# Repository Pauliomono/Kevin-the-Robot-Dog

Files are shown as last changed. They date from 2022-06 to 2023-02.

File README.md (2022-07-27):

# Kevin-the-Robot-Dog

Kevin the Robot Dog is a quadruped I created for a final design project at the University of Notre Dame.

Check him out on Youtube:

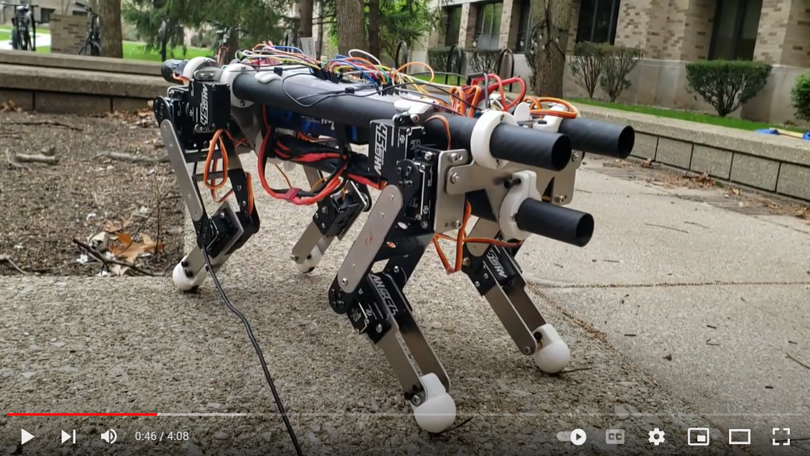
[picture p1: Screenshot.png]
IMAGE ALT TEXT HERE (https://www.youtube.com/watch?v=h35KHhktcEo&t)


For more information check out the final report written on Kevin.

- See Final_Report/Automation_and_Controls_Final_Project_Report.pdf

Recent Changes:

- complete overhaul of code: migrated to PlatformIO in vscode, reorganised functions into separate files
- initial addition of remote control using bluetooth serial (can change modes, walk forward/back & steer)
- improved interpolation for foot positions: switched from linear interpolation to cubic spline interpolation for improved velocity and acceleration control

Active Development:

- adding more remote functionality: telemetry reports to remote, remote realtime PID tuning
- tweaking walking gait/motion to get smoother motion
- adding trim mode (currently drifts instead of staying in one place)

Future plans include:

- Bluetooth remote control
- reworking the entire wiring system (including custom PCB) and battery monitoring circuitry
- overhaul balance control with a more complex model (using analyital dynamics to generate EOMs) of the system & additional tuning
- possible force control? either though current sensors on servos or pressure sensors on feet
- googley eyes to make him cuter
- expanded motion capabilities (jumping, rough surfaces & inclines, possibly stairs)

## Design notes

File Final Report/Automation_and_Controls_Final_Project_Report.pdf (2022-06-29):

AME 40453: Final Project
Technical Memo
Date Submitted: April 28 2022 Dates Performed: Spring 2022 To: Prof. Rumbach
From: Paul Mellor
Subject: Final Project Report

For the Automation and Controls Final Design Project, my project was to build a robotic dog. I

had three goals for this project. My first goal was that the dog would be able to walk forward

& backward and turn left & right on flat surfaces. My second goal was for the robot to actively

balance, so that it did not fall over trying to walk. My third goal was to be able to drive the robot;

I wanted to be able to send movement commands and have the dog move accordingly.

To attack these goals, I came up with the design below.

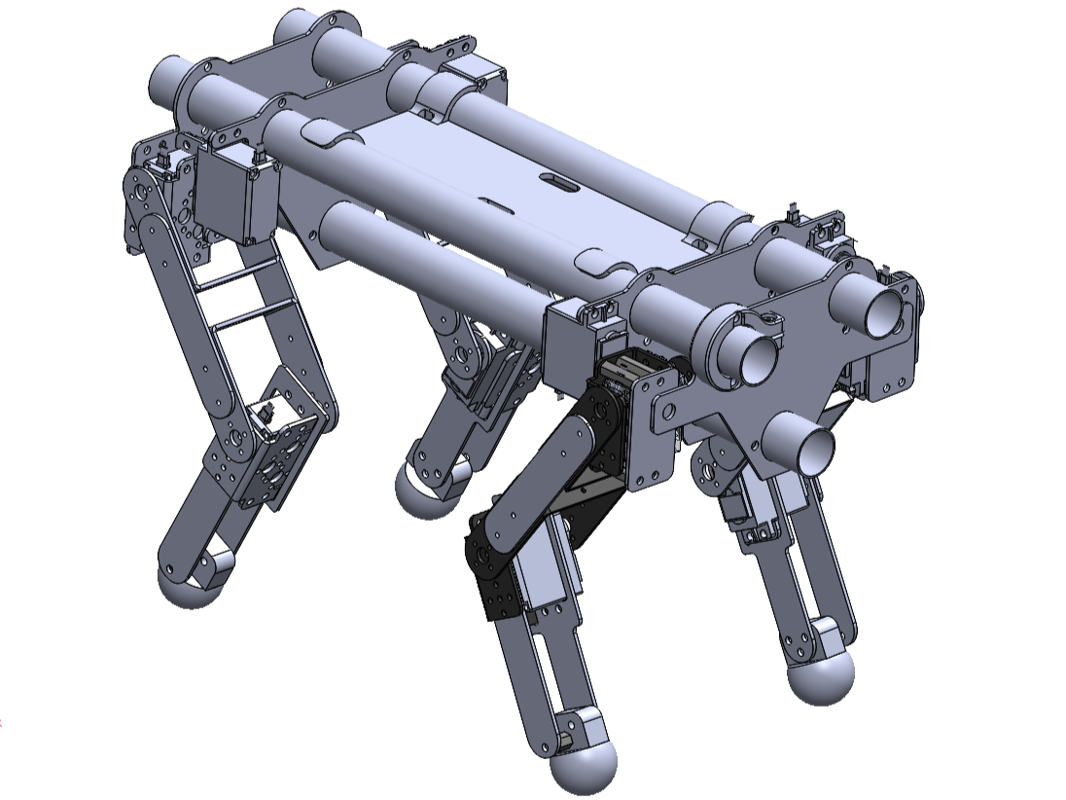
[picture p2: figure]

Figure 1: CAD Model of the Robot

The dog is symmetrical, with 4 identical legs having the knee joint facing the center of the dog.

Each leg has a shoulder joint with 2 DOFs (degrees of freedom) so that the leg can move forward

& backward and left & right. Each joint is driven by a servo motor. Servos are both high torque,

and can be positioned accurately. The construction consists primarily of off the shelf brackets, and

2D fabricated plates. Symmetry and reliance on 2D components greatly simplified the fabrication

process (most components were cut on a waterjet). Additionally, symmetry allowed any kinematic

models for one leg to be applicable to all legs.

The robot’s motion is based on positioning the legs. To walk, each leg steps through 6 way-points

(See Figure 2), and has a specified time to get from 1 point to the next.

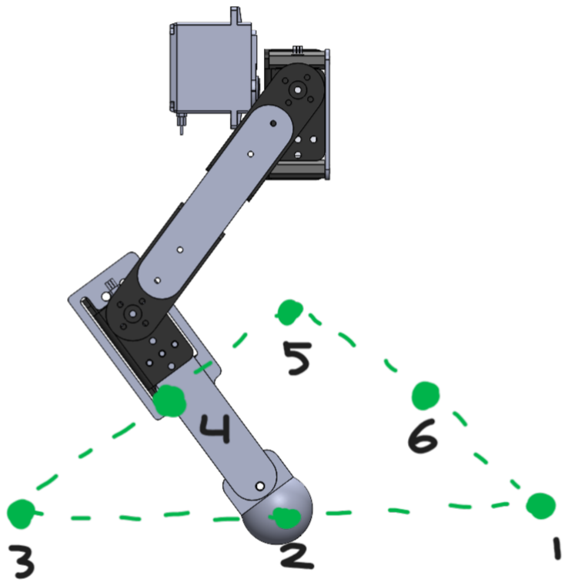
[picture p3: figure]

Figure 2: Path/Points of the Leg’s Walking Motion

To walk, the legs diagonal from one another move in sync, while the opposite two legs are 180◦

out of phase (i.e. if one set of diagonal legs is at point 1, the other set is at point 4). The points are

all timed so that the leg spends half the time on the ground (points 1, 2, 3), and half the time off

the ground (points 4, 5, 6).

Since my approach to moving the legs was to position them in xyz coordinates, I needed an inverse

kinematics model to get the motor angles as a function of xyz coordinates for each leg. The inverse

kinematics was solved using trigonometry (see Figure 3). This was possible because there are only

3 DOF, and because there is a limited area in which the leg can actually move.

To solve for θshoulder1 (the shoulder joint moving in the yz plane) using xyz coordinates (as depicted

in figure 2) the equation below is used.

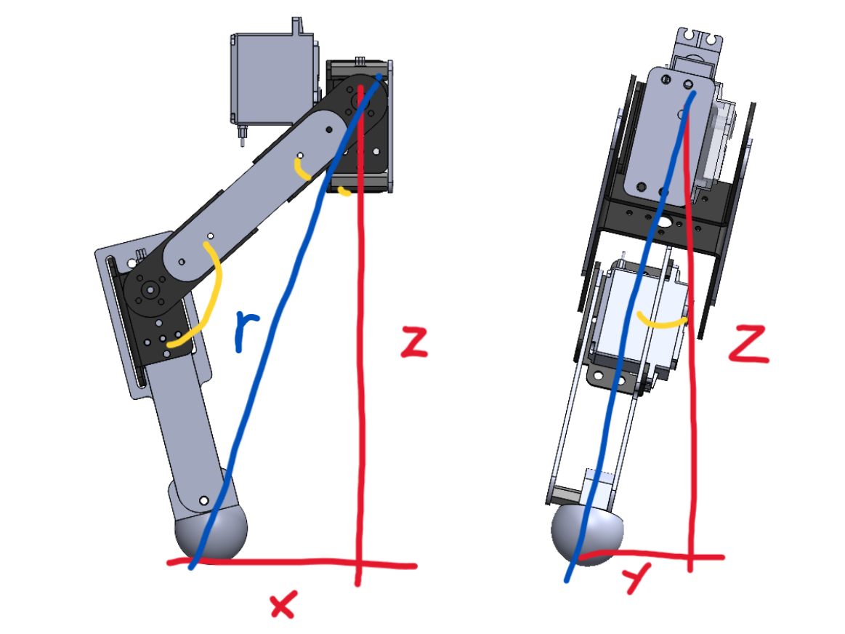
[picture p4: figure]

Figure 3: Trig Used to Calculate Inverse Kinematics

θshoulder1 = arctan(

y
z
) | (1)

To solve for θshoulder2 (the shoulder joint moving in the xz plane) and θknee an intermediate length

r is calculated by:

r =

p
z

2 +x

2
(2)

This enabled my to use law of cosines to solve for θshoulder2 and θknee below.

θshoulder2 = arccos(

r

2

2Lr

)−arctan(

x
z
); | (3)

θknee = arccos(

2L

2 −r

2

2L

2

); | (4)

where L is the length of the limbs (both limbs are equal length).

To actively balance the robot, a controller was designed to maintain 0◦of pitch and roll by keeping the 4 feet of the robot centered below the COM (center of mass). An accelerometer/gyroscopic

sensor was placed on the body of the robot, and returned θpitch and θroll of the robot. To control

the pitch, the x position of the legs were adjusted using the PID control equation below:

x = xopenloop +hsin(kp(θpitchs −θpitch) +kI

Z
(θpitchs −θpitch)dt +kd∆θpitch) | (5)

where xopenloop is the x value before the balance calculation, h is the height of the shoulder joint

to the ground, θpitchs

is the target pitch angle (0◦ ) and kp, kI and kd are the PID control constants.

SImilarly, to control the roll, the y position of the legs were adjusted using the PID control equation

below:

y = yopenloop +hsin(kp(θrolls −θroll) +kI

Z
(θrolls −θroll)dt +kd∆θroll) | (6)

here yopenloop is the x value before the balance calculation, h is the height of the shoulder joint to

the ground, θpitchs

is the target pitch angle (0◦ ) and kp, kI and kd are different PID control constants.

The resulting robot is shown below.

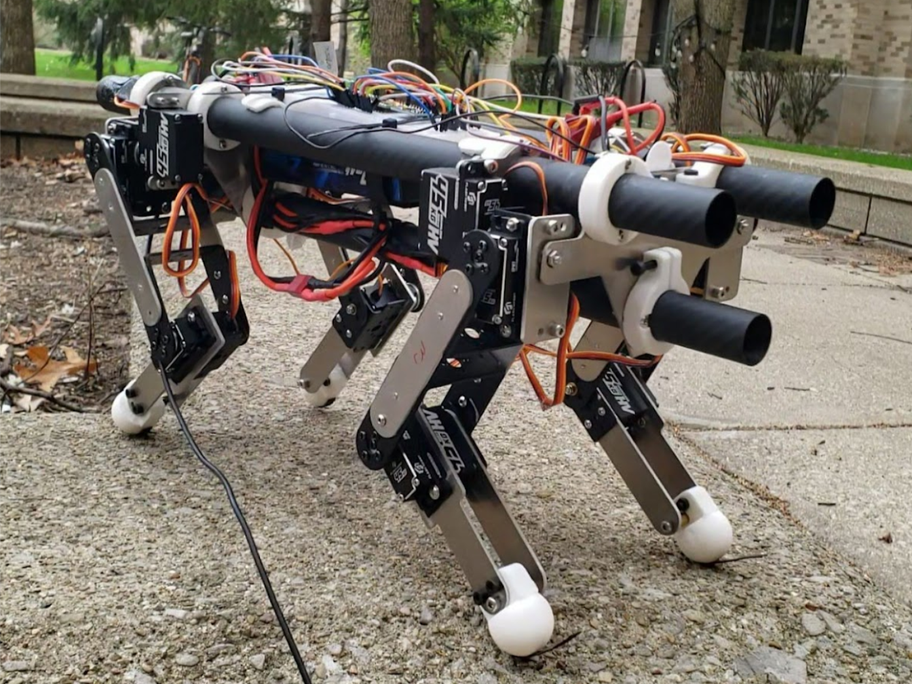
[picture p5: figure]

Figure 4: Photo of the Final Robot

It effectively met the goals initially set out for this project. The dog can walk forward & backward

and turn left & right without falling over. The balance controller is effective enough that it can even

handle some uneven surfaces. It takes serial inputs sent from a laptop to determine what direction

to move.

There are still a number of issues with the robot. First, it is not completely remote control. The

dog is still tethered to a laptop to send commands. This would make the robot much easier to

use. Second, electrical noise occasionally interferes with the signals to the motors, causing them to

glitch out. Shielding and shortening the signal wires would make leg movements more consistent

and predictable. Third, the balance control is still rudimentary. If a more sophisticated controller

was used, the robot could move more smoothly and handle significantly rougher terrain.

Overall, I am pleased with the results for this project.

References:

[1] James Bruton Youtube Channel, https://youtu.be/aDlHz0W0R44
[2] James Bruton Github, https://github.com/XRobots/miniDogV2
[3] MPU6050 Github, https://github.com/electroniccats/mpu6050

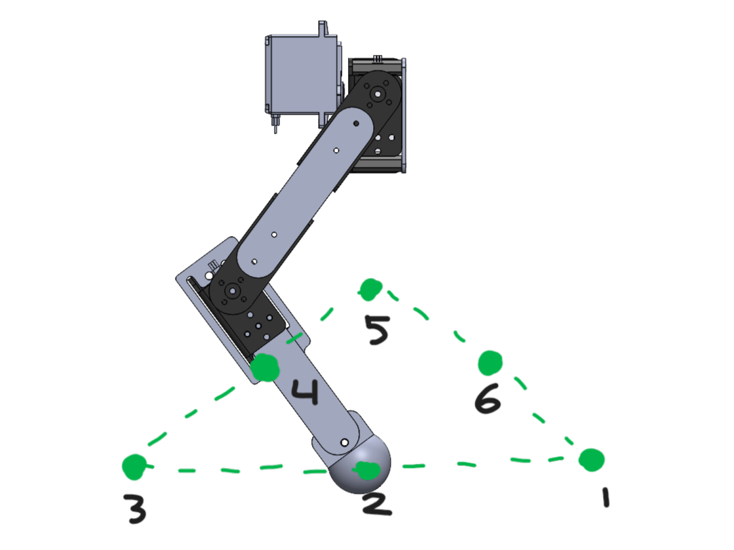
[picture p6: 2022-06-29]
Final Report/Screenshot (202).png

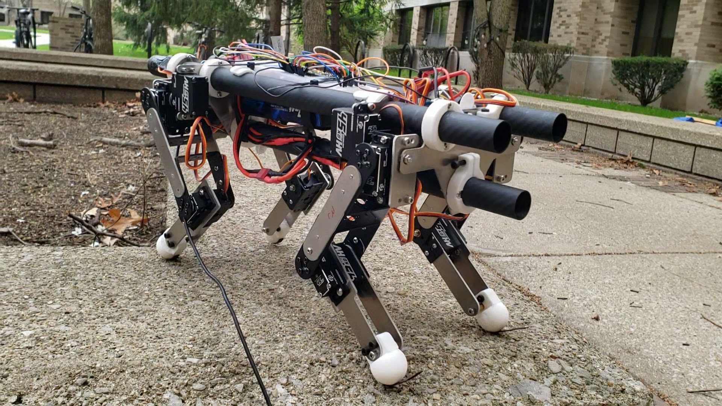
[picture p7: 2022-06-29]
20220424_132255_exported_5930.jpg

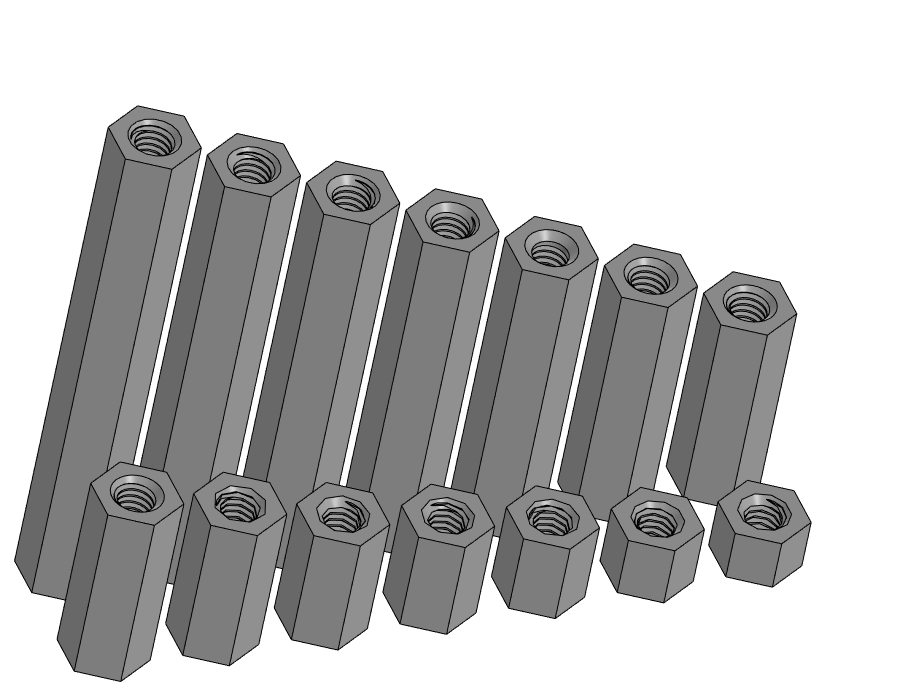
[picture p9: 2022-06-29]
CAD Files/hex-spacer-standoff-nut-m4-l5-l50-1.snapshot.3/hex spacer standoff nut M4 L5-L50.png

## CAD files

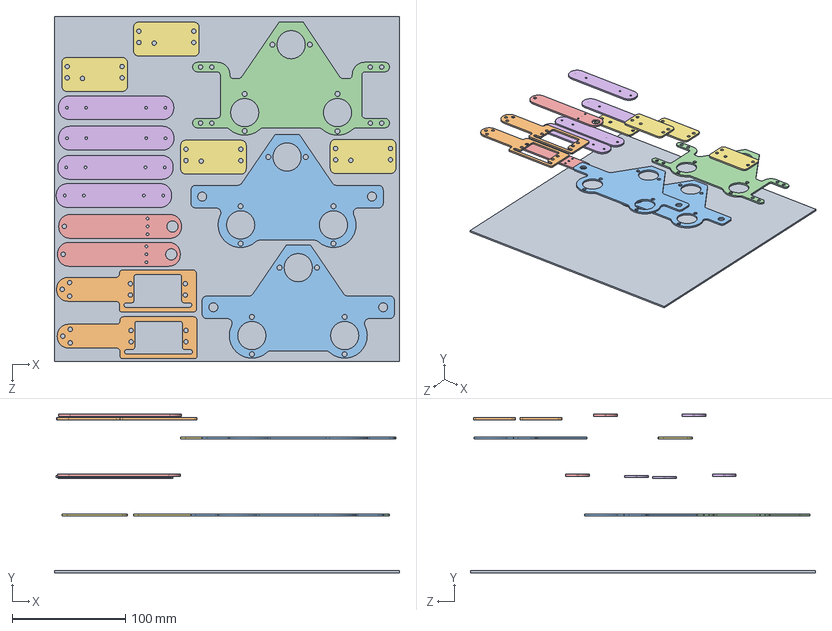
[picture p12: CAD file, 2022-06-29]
CAD Files/DXF files/waterjet_setup.SLDASM
304.8 x 140.1 x 304.8 mm
stock
leg_lower_1 x 2
hip_frame_2 x 2
hip_frame_1
leg_lower_2 x 2
leg_upper_1 x 4
hip_1 x 4

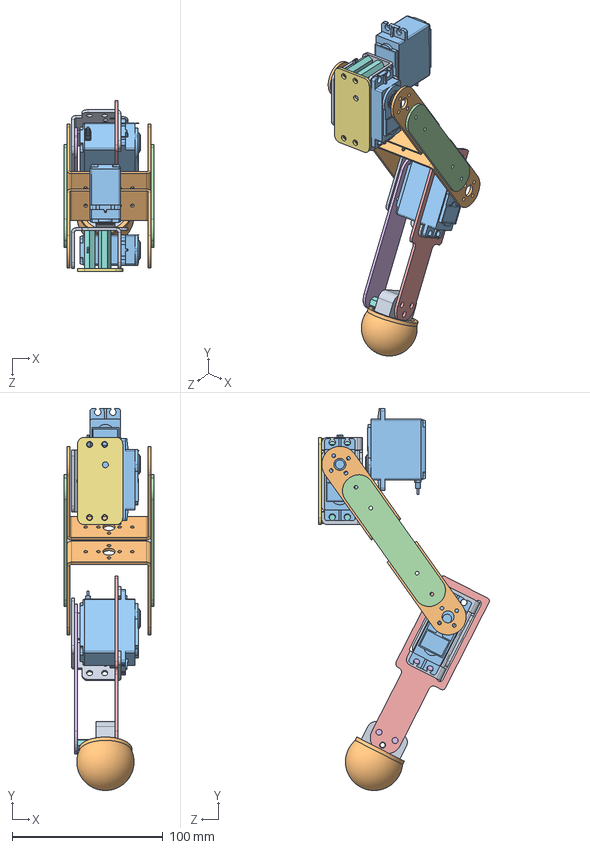
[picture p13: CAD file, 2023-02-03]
CAD Files/leg.SLDASM
60.0 x 253.4 x 113.4 mm
Multi Purpose Bracket x 2
U Long Bracket x 2
Parça2 - Kopya x 3
leg_upper_1 x 2
leg_lower_1
leg_lower_2
hip_1
hex spacer standoff nut M4 L25.stp x 5
foot
foot_grip

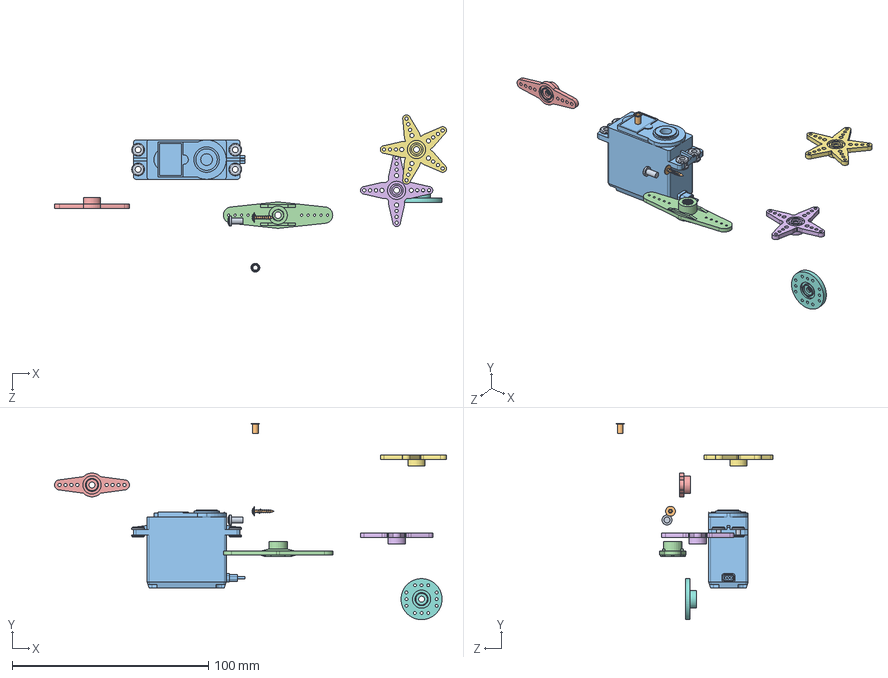
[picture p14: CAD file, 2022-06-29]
CAD Files/servo motor/Montaj2.SLDASM
199.6 x 100.0 x 80.1 mm
Parça10
parça11,
Parça2
Parça3
Parça4
Parça5
Parça6
Parça8
parça9 x 4

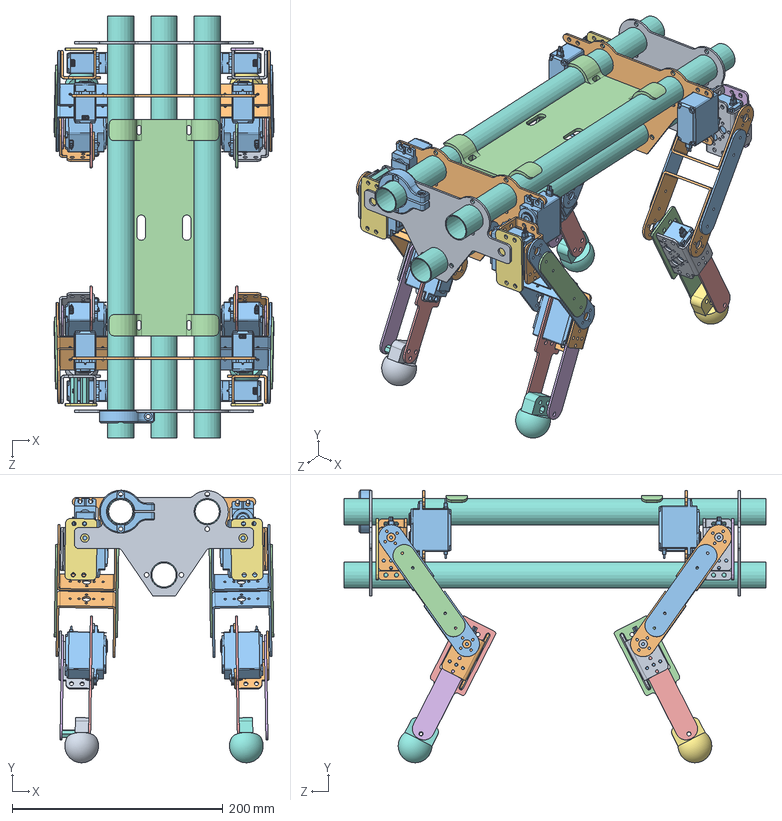
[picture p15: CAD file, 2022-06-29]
CAD Files/Robo_Doggo.SLDASM
208.1 x 258.4 x 400.0 mm
Multi Purpose Bracket x 2
U Long Bracket x 2
Parça2 - Kopya x 12
leg_upper_1 x 2
leg_lower_1
leg_lower_2
hip_1
hex spacer standoff nut M4 L25.stp x 5
foot
MirrorMulti Purpose Bracket x 4
MirrorU Long Bracket x 4
Mirrorleg_upper_1 x 4
Mirrorleg_lower_1 x 2
Mirrorleg_lower_2 x 2
Mirrorhip_1 x 2
Mirrorfoot x 2
MirrorMirrorMulti Purpose Bracket x 2
MirrorMirrorU Long Bracket x 2
MirrorMirrorleg_upper_1 x 2
MirrorMirrorleg_lower_1
MirrorMirrorleg_lower_2
MirrorMirrorhip_1
MirrorMirrorfoot
frame_tube_1 x 3
hip_frame_2 x 2
hip_frame_1 x 2
tube_clamp_1
electronics_mount

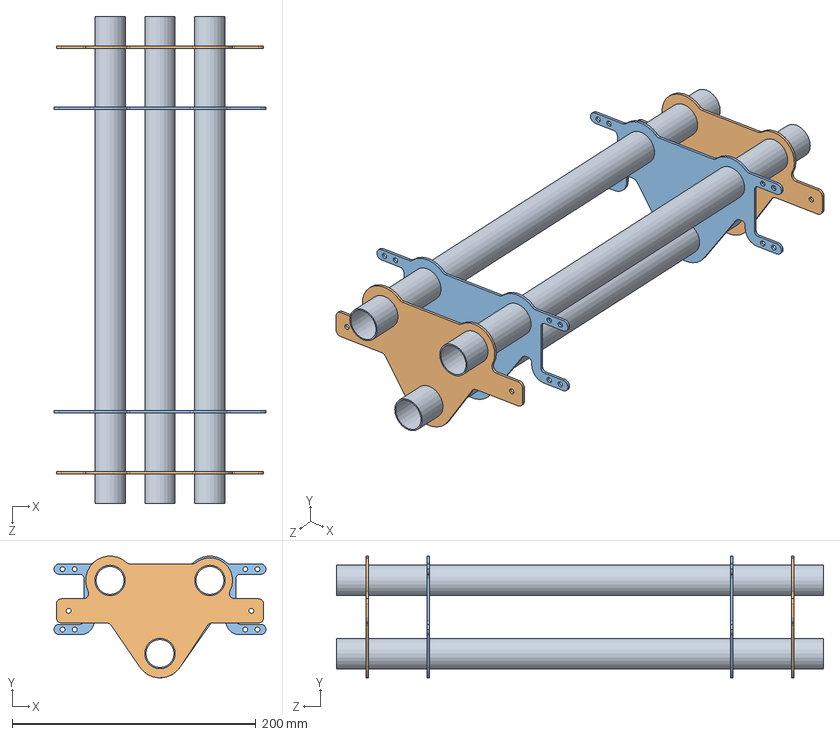
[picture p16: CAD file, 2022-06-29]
CAD Files/Frame.SLDASM
174.0 x 99.8 x 400.0 mm
frame_tube_1 x 3
hip_frame_2 x 2
hip_frame_1 x 2

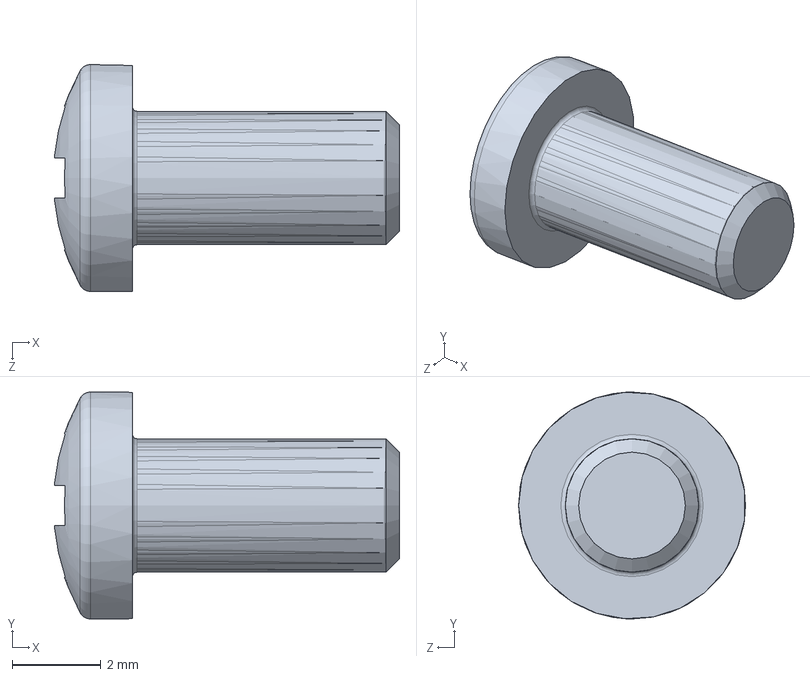
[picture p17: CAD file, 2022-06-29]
CAD Files/servo motor/parça12.SLDPRT
7.75 x 5.10 x 5.10 mm

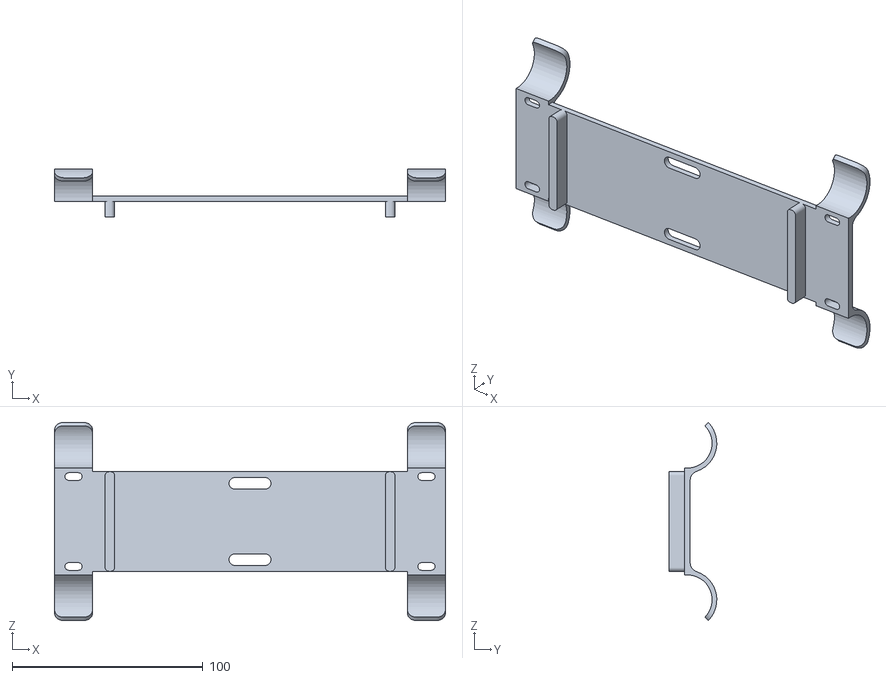
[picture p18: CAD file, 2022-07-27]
CAD Files/STL Files/electronics_mount_v2.STL
205.0 x 25.0 x 103.9

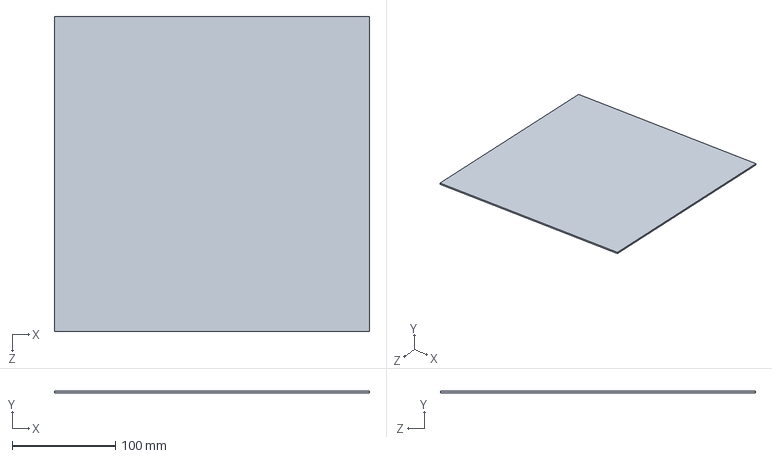
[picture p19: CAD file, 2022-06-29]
CAD Files/DXF files/stock.SLDPRT
304.8 x 2.00 x 304.8 mm

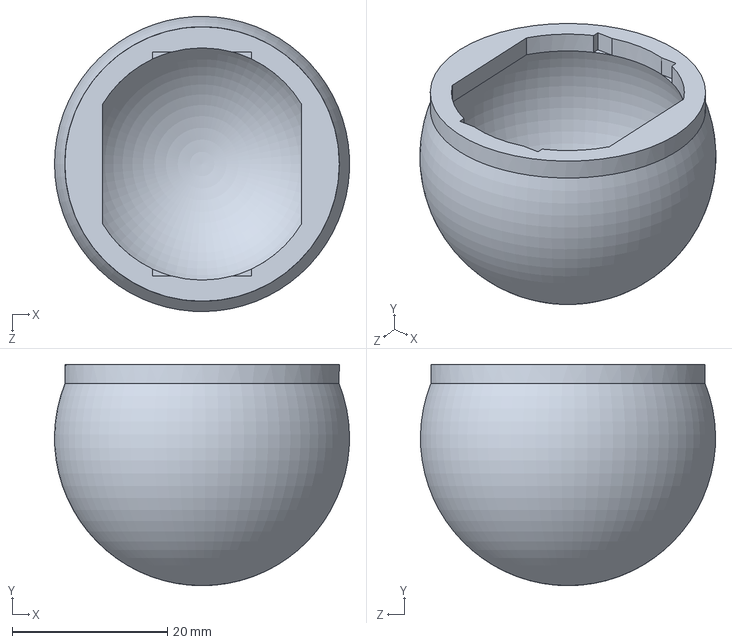
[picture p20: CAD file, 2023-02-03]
CAD Files/foot_grip.SLDPRT
38.0 x 28.5 x 38.0 mm

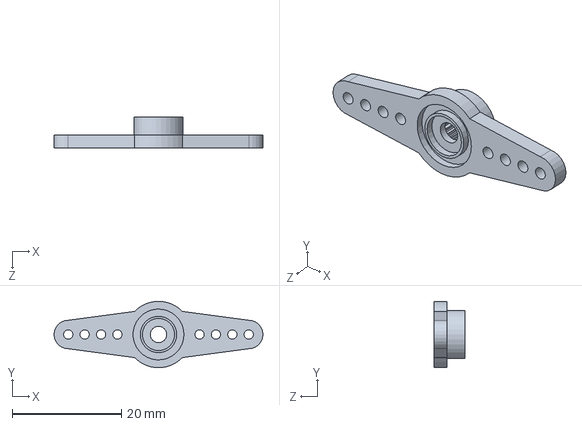
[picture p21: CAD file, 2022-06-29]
CAD Files/servo motor/Parça4.SLDPRT
38.2 x 12.1 x 5.60 mm

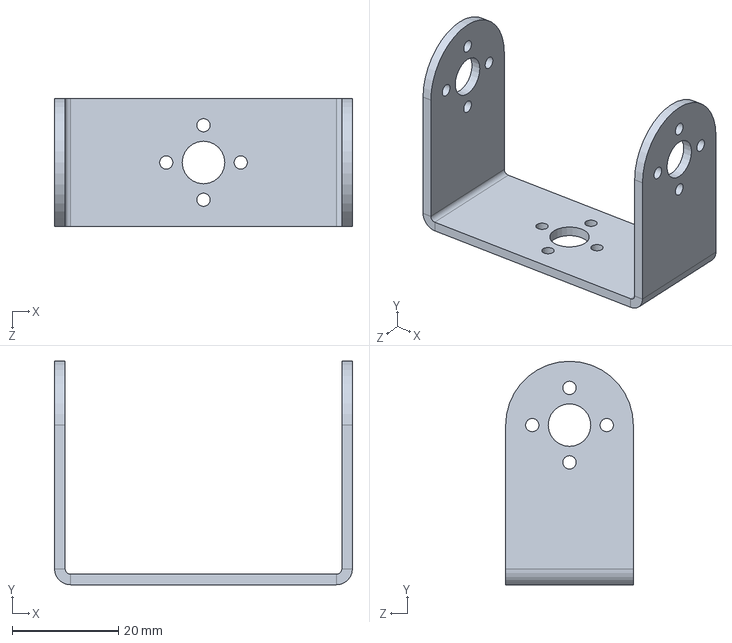
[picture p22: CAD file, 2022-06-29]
CAD Files/servo-brackets-2.snapshot.3/U Bracket.SLDPRT
56.0 x 42.0 x 24.0 mm

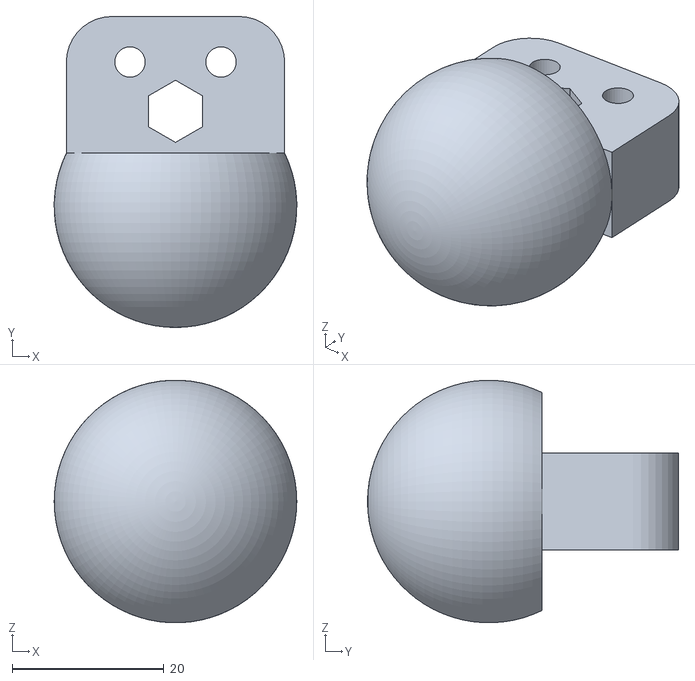
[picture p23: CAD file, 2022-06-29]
CAD Files/STL Files/foot.STL
32.0 x 41.0 x 32.0

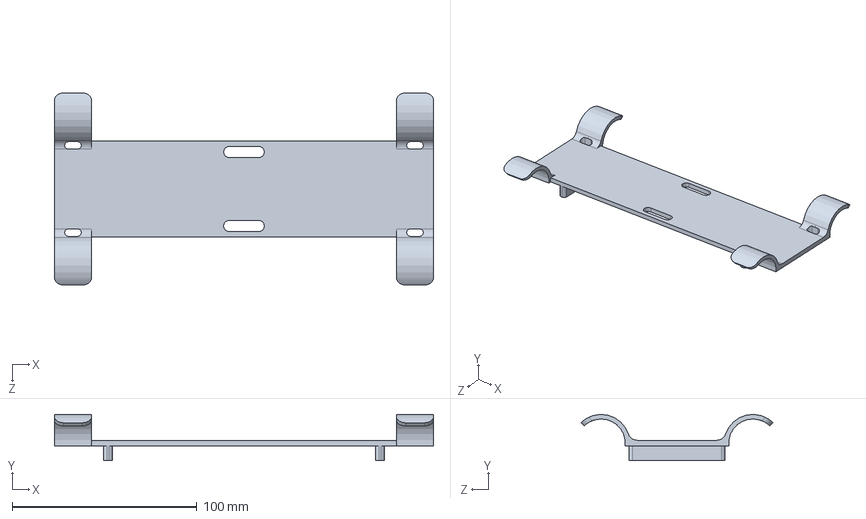
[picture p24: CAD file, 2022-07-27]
CAD Files/electronics_mount.SLDPRT
205.0 x 25.0 x 103.9 mm

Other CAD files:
CAD Files/Mirrorleg1.SLDASM
CAD Files/MirrorMirrorleg.SLDASM
CAD Files/Mirrorleg.SLDASM
CAD Files/servo-brackets-2.snapshot.3/MirrorMirrorU Long Bracket.SLDPRT
CAD Files/DXF files/waterjet_path_2.DXF
CAD Files/98434A706_18-8 Stainless Steel Female Hex Thread Adapter.SLDPRT
CAD Files/DXF files/waterjet_path.DXF
CAD Files/DXF files/waterjet_setup.SLDDRW
CAD Files/DXF files/waterjet_setup_2.SLDDRW
CAD Files/MirrorMirrorhip_1.SLDPRT
CAD Files/MirrorMirrorleg_lower_1.SLDPRT
CAD Files/MirrorMirrorleg_lower_2.SLDPRT
CAD Files/MirrorMirrorleg_upper_1.SLDPRT
CAD Files/Mirrorhip_1.SLDPRT
CAD Files/Mirrorleg_lower_1.SLDPRT
CAD Files/Mirrorleg_lower_2.SLDPRT
CAD Files/Mirrorleg_upper_1.SLDPRT
CAD Files/PCB_guard.SLDPRT
CAD Files/STL Files/PCB_guard.STL
CAD Files/STL Files/electronics_mount.STL
CAD Files/STL Files/foot_grip.STL
CAD Files/STL Files/leg_lower_1.STL
CAD Files/STL Files/leg_lower_2.STL
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

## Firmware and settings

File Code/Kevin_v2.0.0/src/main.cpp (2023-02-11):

#include <Arduino.h>
#include <Servo.h>
#include <I2Cdev.h>
#include <MPU6050_6Axis_MotionApps20.h>
#include <PID_v1.h>

#include <Adafruit_PWMServoDriver.h>

#include "interpolation.h"
#include <remote_control.h>
#include "IMU.h"
#include <servos.h>
#include <kinematics.h>
#include <balance_controller.h>
#include <debugging.h>
#include <configuration.h>
#include <Smoothed.h>

// rc globals
int xxx;
int yyy;
int packet;
int packet2;
int t_old_rc;

// debug tools
int debug_time;
int debug_point = 1;
int n_debug_points = 3;

// code control vars
int state_time;
int interpolation_interval = 20; // keep this a constant - servos won't update quicker than 20ms
int n_interps;
int state = 1;
int mode = 0;
int n_states = 6;

// timing vars
float t0 = 0;
float tf = 1000;
int t;
int t_old;
int t_old_state;
int comm_timer;
int imu_timer;
int mode_timer;

// SoftwareSerial Remote (21, 20);
String datapacket;
bool data_recieved = 0;
int xxx_old = 0;
int yyy_old = 0;
int tune_precision = 0;
float x_tune = 0;
float y_tune = 0;
int tune_mode = 0;

// button stuff

// foot position vars
float L = 124;
float l_pitch = 156;
float l_roll = 76;
struct points x1;
struct points yy1;
struct points z1;
struct points x2;
struct points yy2;
struct points z2;
struct points x3;
struct points yy3;
struct points z3;
struct points x4;
struct points yy4;
struct points z4;
struct r shoulders;
// these all need to be measured
float L_body = 100;
float L_shoulder = 100;
float L_COM = 100;
float roll_input = 0;
float pitch_input = 0;
float yaw_input = 0;

// leg position control vars
float x_dist = 0;
float z_dist = 0;
double steer1 = 0;
float steer2 = 0;
double pitch1 = 0;
double pitch_angle1 = 0;
float pitch2 = 0;
double pitch_angle2 = 0;
double roll1 = 0;
double roll_angle1 = 0;
float roll2 = 0;
double roll_angle2 = 0;
double yaw1;
float yaw2;
float step_height = 20;
float leg_height = 180;
int control_increment = 20;
int motion_limit = 30;

double yaw;
double pitch;
double roll;
double x_accel;
double y_accel;
double z_accel;

double yaw_target = 0;
double pitch_target = 0;
double roll_target = 0;
double yaw_commanded = 0;
double pitch_commanded = 0;
double roll_commanded = 0;

#ifdef PID_BALANCE_ENABLE
// PID setup
float kpp = 0.0; //.45*kup;
float kip = 0.0; //.54*kup/tup;
float kdp = 0.0; //.54*kup*tup;
PID pitchPID(&pitch, &pitch_commanded, &pitch_target, kpp, kip, kdp, DIRECT);

float kpr = 0.0; //.05;
float kir = 0.0; //.01;
float kdr = 0.0; //.01;
PID rollPID(&roll, &roll_commanded, &roll_target, kpr, kir, kdr, DIRECT);

float kpy = 0.0;
float kiy = 0.0;
float kdy = 0.0;
PID yawPID(&yaw, &yaw_commanded, &yaw_target, kpy, kiy, kdy, DIRECT);

#endif
/*
double aTuneStep=50, aTuneNoise=1, aTuneStartValue=100;
unsigned int aTuneLookBack=20;

boolean tuning = true;

PID_ATune aTune(&pitch, &pitch1);
*/

// remote control vars
int input;
char c = ' ';

bool newData = false;

// servo objects
Servo hip1;
Servo shoulder1;
Servo knee1;
Servo hip2;
Servo shoulder2;
Servo knee2;
Servo hip3;
Servo shoulder3;
Servo knee3;
Servo hip4;
Servo shoulder4;
Servo knee4;
Adafruit_PWMServoDriver pwm = Adafruit_PWMServoDriver();
Smoothed<int> hip_feedback_angle;

struct angles leg1;
struct angles leg2;
struct angles leg3;
struct angles leg4;

struct angles leg1_final;
struct angles leg2_final;
struct angles leg3_final;
struct angles leg4_final;

// IMU setup
MPU6050 mpu;

bool blinkState = false;

// MPU control/status vars
bool dmpReady = false;  // set true if DMP init was successful
uint8_t mpuIntStatus;   // holds actual interrupt status byte from MPU
uint8_t devStatus;      // return status after each device operation (0 = success, !0 = error)
uint16_t packetSize;    // expected DMP packet size (default is 42 bytes)
uint16_t fifoCount;     // count of all bytes currently in FIFO
uint8_t fifoBuffer[64]; // FIFO storage buffer

// orientation/motion vars
Quaternion q;        // [w, x, y, z]         quaternion container
VectorInt16 aa;      // [x, y, z]            accel sensor measurements
VectorInt16 aaReal;  // [x, y, z]            gravity-free accel sensor measurements
VectorInt16 aaWorld; // [x, y, z]            world-frame accel sensor measurements
VectorFloat gravity; // [x, y, z]            gravity vector
float euler[3];      // [psi, theta, phi]    Euler angle container
float ypr[3];        // [yaw, pitch, roll]   yaw/pitch/roll container and gravity vector

volatile bool mpuInterrupt = false;

// PWM board setup
const int OscillatorFrequency = 25725000;
const int PWMFreq = 50;
const int startup_delay = 5000;

// input shaper globals
double frequency;
double amplitude;
int root_time;
int root_time_counter; // global?
double low_trigger;
double high_trigger;
double peak;
double trough;
int peak_time;
int trough_time;
int root_time_1; // global?
int root_time_2;
bool trigger_state; // global?
int step;           // global
int roots_delta;
double mpeak;
double mtrough;
int t_sin_init;
int phase_time;

// comms globals
int comm_receive_step = 1;
int time_stamp;
uint16_t checksum;
char mnemonic[7];
data_type comm_data;
char double_buffer[8];
comm comm_results;
bool new_data;
char data_byte;
char telem_packet[24] = {0, 0, 0, 0, 0, 0, 0, 0, 0, 0, 0, 0, 0, 0, 0, 0, 0, 0, 0, 0, 0, 0, 0, 0};

uint8_t serial_buffer[SERIAL_BUFFER_SIZE];

void setup() // setup and initialization code
{
      // initialize serial bus
      Serial.begin(115200);
      delay(2000);
      Serial4.begin(115200);
      Serial4.addMemoryForWrite(serial_buffer, SERIAL_BUFFER_SIZE);
      Serial.println("Kevin v2.0.0");
      Serial.println("-----------------------------------------------------------------");
      Serial.println("Begin Kevin startup:");
      Serial.println("-----------------------------------------------------------------");

      // pin setup
      pinMode(0, OUTPUT);
      pinMode(1, OUTPUT);
      pinMode(2, OUTPUT);
      pinMode(3, OUTPUT);
      pinMode(4, OUTPUT);
      pinMode(5, OUTPUT);
      pinMode(6, OUTPUT);
      pinMode(7, OUTPUT);
      pinMode(8, OUTPUT);
      pinMode(9, OUTPUT);
      pinMode(10, OUTPUT);
      pinMode(11, OUTPUT);
      pinMode(13, OUTPUT);
      digitalWrite(13, HIGH);
      pinMode(A6, INPUT);
      hip_feedback_angle.begin(SMOOTHED_AVERAGE, 8);
      hip_feedback_angle.add(analogRead(A6));

      Serial.println("Pin Modes Set");

#ifdef SERVO_PWM_INTERNAL
      // initialize servos
      Serial.println("PWM signaling set to internal");
      hip1.attach(0);
      shoulder1.attach(1);
      knee1.attach(2);
      hip2.attach(3);
      shoulder2.attach(4);
      knee2.attach(5);
      hip3.attach(6);
      shoulder3.attach(7);
      knee3.attach(8);
      hip4.attach(9);
      shoulder4.attach(10);
      knee4.attach(11);
      Serial.println("Servo motors attached");
#endif

#ifdef SERVO_PWM_EXTERNAL
      // initialize pwm board
      Serial.println("PWM signaling set to external");
      pwm.begin();
      pwm.setOscillatorFrequency(OscillatorFrequency); // 25725000
      pwm.setPWMFreq(PWMFreq);                         // 50
      Serial.print("PWM oscillator frequency set to ");
      Serial.print(OscillatorFrequency);
      Serial.println(" Hz");
      Serial.print("PWM frequency set to ");
      Serial.print(PWMFreq);
      Serial.println(" Hz");
      Serial.println("PWM setup complete");
#endif

      state = 0;
      get_xyz();
      // set initial leg position
      Serial.println("Initializing leg kinematics:");
      shoulders = attitude_model(roll_commanded, pitch_commanded, yaw_commanded);
      x1.pos = x1.pos_f;
      yy1.pos = yy1.pos_f;
      z1.pos = z1.pos_f;
      x2.pos = x2.pos_f;
      yy2.pos = yy2.pos_f;
      z2.pos = z2.pos_f;
      x3.pos = x3.pos_f;
      yy3.pos = yy3.pos_f;
      z3.pos = z3.pos_f;
      x4.pos = x4.pos_f;
      yy4.pos = yy4.pos_f;
      z4.pos = z4.pos_f;
      Serial.println("leg 0 position set");

      // velocities
      x1.vel = x1.vel_f;
      yy1.vel = yy1.vel_f;
      z1.vel = z1.vel_f;
      x2.vel = x2.vel_f;
      yy2.vel = yy2.vel_f;
      z2.vel = z2.vel_f;
      x3.vel = x1.vel;
      yy3.vel = -yy1.vel;
      z3.vel = z1.vel;
      x4.vel = x2.vel;
      yy4.vel = yy2.vel;
      z4.vel = z2.vel;
      Serial.println("leg 0 velocity set");

      // accelerations
      x1.accel = x1.accel_f;
      yy1.accel = yy1.accel_f;
      z1.accel = z1.accel_f;
      x2.accel = x2.accel_f;
      yy2.accel = yy2.accel_f;
      z2.accel = z2.accel_f;
      x3.accel = x1.accel;
      yy3.accel = -yy1.accel;
      z3.accel = z1.accel;
      x4.accel = x2.accel;
      yy4.accel = yy2.accel;
      z4.accel = z2.accel;
      Serial.println("leg 0 acceleration set");

      Serial.println("leg final acceleration set");
      Serial.println("leg kinematics initialization complete.");

      // calculate inverse kinematics
      IK_interpolate2(t0, tf, t);
      Serial.println("Initial kinematics calculated");

      leg1 = IK_final(x1.pos, yy1.pos, z1.pos);
      leg2 = IK_final(x2.pos, yy2.pos, z2.pos);
      leg3 = IK_final(x3.pos, yy3.pos, z3.pos);
      leg4 = IK_final(x4.pos, yy4.pos, z4.pos);

      // write angles to servos
      write_servos();
      Serial.println("Legs enable");

      // debug & calibrate servo angles
      /*
      leg1.hip = 0;
      leg1.shoulder = 45;
      leg1.knee = 90;
      leg2.hip = 0;
      leg2.shoulder = 45;
      leg2.knee = 90;
      leg3.hip = 0;
      leg3.shoulder = 45;
      leg3.knee = 90;
      leg4.hip = 0;
      leg4.shoulder = 45;
      leg4.knee = 90;
      */

      // IMU setup
      Serial.println("IMU setup start");
      delay(2500);
      IMU_setup();
      Serial.println("IMU setup complete");

      // sets # of points interpolated between servo positions: more = smoother
      // edit - currently locked servo updates to 50hz due to servo limitations
      n_interps = state_time / interpolation_interval;
      // PID start

#ifdef PID_BALANCE_ENABLE
      // yawPID.SetMode(AUTOMATIC);
      yawPID.SetOutputLimits(-20, 20);
      // yawPID.SetSampleTime(10);

      // pitchPID.SetMode(AUTOMATIC);
      pitchPID.SetOutputLimits(-20, 20);
      // pitchPID.SetSampleTime(10);

      rollPID.SetMode(AUTOMATIC);
      rollPID.SetOutputLimits(-20, 20);
      rollPID.SetSampleTime(10);
#endif

#ifdef INPUT_SHAPING
      Serial.println("Starting input shaper");
      step = 0;
      int n_sample_count = 0;
      int n_sample_size = 60; // must be greater than 1 and even
      while (n_sample_count < n_sample_size)
      {
            hip_feedback_angle.add(analogRead(A6));
            Serial.print((float)-15 / 44 * (hip_feedback_angle.get() - 491) + 90);
            Serial.print("\t");
            Serial.print(90 + leg3.hip);
            Serial.print("\t");
            Serial.print(millis());
            Serial.print("\t");
            Serial.print(roots_delta);
            Serial.print("\t");
            Serial.print(frequency);
            Serial.print("\t");
            Serial.print(amplitude);
            Serial.print("\t");
            Serial.println(n_sample_count);

            n_sample_count = input_shape_setup(90 + leg3.hip, (float)-15 / 44 * (hip_feedback_angle.get() - 491) + 90, n_sample_count);
            delay(2);
      }
      Serial.print("Determined frequency: ");
      Serial.print(frequency);
      Serial.println(" Hz");
      Serial.print("Determined amplitude: +/-");
      Serial.print(amplitude);
      Serial.println(" deg");

      // frequency = 6;
      // amplitude = 4;
#endif

      Serial.println("-----------------------------------------------------------------");
      Serial.print("Kevin startup complete. Pausing for ");
      Serial.print(startup_delay);
      Serial.println(" milliseconds.");
      Serial.println("-----------------------------------------------------------------");
      delay(startup_delay);
}

void loop()
{
      t = millis();
#ifdef COMM_MODE_STRING
      remoteIO();
#endif

#ifdef COMM_MODE_INT
      remoteIO();
#endif

#ifdef COMM_MODE_DESCRIPTIVE

      if (comm_timer != t)
      {
            comm_timer = t;
            comms_send();
      }

      comms_receive();
      comms_interpreter();
#endif

#ifdef DEBUG_TIMER
      // debug_timer(); // 1
#endif

// get IMU data (to add)
#ifdef IMU_ENABLE

      if (imu_timer != t)
      {
            get_IMU_data();
            yaw = ypr[0] * 180 / M_PI;
            pitch = ypr[2] * 180 / M_PI;
            roll = (double)ypr[1] * 180 / M_PI;
            x_accel = aaWorld.x;
            y_accel = aaWorld.y;
            z_accel = aaWorld.z;
            imu_timer = t;
      }

#endif

#ifdef DEBUG_TIMER
      // debug_timer(); // 2
#endif

#ifdef DEBUG_TIMER
      // debug_timer(); // 3
#endif
      // roll_angle1 = constrain(roll_angle1,-20,20);
      // roll2PID.Compute();
      roll_angle2 = constrain(roll_angle2, -40, 40);
      // pitch2PID.Compute();

      // PID_tune();

      // mode state timing control
      if ((t % 250 == 0) && (mode_timer != t))
      {
            if (mode == 0)
            {
                  state_time = 1000;
                  n_interps = state_time / interpolation_interval;
            }
            if (mode == 1)
            {
                  state_time = 100;
                  n_interps = state_time / interpolation_interval;
            }
            if (mode == 2)
            {
                  state_time = 100;
                  n_interps = state_time / interpolation_interval;
            }
            if (mode == 3)
            {
                  state_time = 1000;
                  n_interps = state_time / interpolation_interval;
            }
            if (mode == 4)
            {
                  state_time = 1000;
                  n_interps = state_time / interpolation_interval;
            }
            mode_timer = t;
      }

      // static test modes
      if ((mode == 0) || (mode == 2))
      {
            // timing control
            if (t - t_old_state >= state_time)
            {
                  t_old_state = t;
                  t0 = t;
                  tf = t0 + state_time;

                  // define leg positions
                  state = 0;
                  get_xyz();
            }

#ifdef DEBUG_TIMER
            debug_timer(); // 4
#endif
                           // interpolation timing
            if (t - t_old >= interpolation_interval)
            {
                  t_old = t;
#ifdef PID_BALANCE_ENABLE
                  get_xyz();
#endif

                  // interpolate to final angles
                  // IK_interpolate2(t - state_time/2, t + state_time/2, t);
                  IK_interpolate2(t0, tf, t);

                  leg1 = IK_final(x1.pos, yy1.pos, z1.pos);
                  leg2 = IK_final(x2.pos, yy2.pos, z2.pos);
                  leg3 = IK_final(x3.pos, yy3.pos, z3.pos);
                  leg4 = IK_final(x4.pos, yy4.pos, z4.pos);
                  // write angles to servos
                  write_servos();

#ifdef PRINT_LEG_XYZ
                  Serial.print(x_dist);
                  Serial.print("\t");
                  Serial.print(steer2);
                  Serial.print("\t");
                  Serial.print(x1.pos);
                  Serial.print("\t");
                  Serial.print(yy1.pos);
                  Serial.print("\t");
                  Serial.print(z1.pos);
                  Serial.println("\t");
#endif

#ifdef DEBUG_TIMER
                  debug_timer(); // 7
#endif
            }
      }
      // balance mode
      if (mode == 3)
      {
            // timing control
            if (t - t_old_state >= state_time)
            {
                  t_old_state = t;
                  t0 = t;
                  tf = t0 + state_time;
                  state = 3;
                  // define leg positions
                  get_xyz();
            }

            // interpolation timing
            if (t - t_old >= interpolation_interval)
            {
                  t_old = t;
#ifdef PID_BALANCE_ENABLE
                  get_xyz();
#endif

                  // interpolate to final angles
                  IK_interpolate2(t0, tf, t);

                  leg1 = IK_final(x1.pos, yy1.pos, z1.pos);
                  leg2 = IK_final(x2.pos, yy2.pos, z2.pos);
                  leg3 = IK_final(x3.pos, yy3.pos, z3.pos);
                  leg4 = IK_final(x4.pos, yy4.pos, z4.pos);
                  // write angles to servos
                  write_servos();
            }
      }

      // walking mode
      if (mode == 1)
      {

            // states controller/timer
            if (t - t_old_state >= state_time)
            {
                  t_old_state = t;
                  t0 = t;
                  tf = t0 + state_time;
                  state++;

                  if (state > N_STATES)
                  {
                        state = 1;
                  }
                  get_xyz();
            }

            // walking states - breaks step motion into 6 points (states)

            // interpolation timing
            if (t - t_old >= interpolation_interval)
            {
                  t_old = t;
#ifdef PID_BALANCE_ENABLE
                  get_xyz();
#endif
                  // debug

#ifdef PRINT_LEG_XYZ
                  Serial.print(state);
                  Serial.print("\t");
                  Serial.print(x1.pos);
                  Serial.print("\t");
                  Serial.print(yy1.pos);
                  Serial.print("\t");
                  Serial.print(z1.pos);
                  Serial.print("\t");
#endif

                  // interpolate to final angles
                  IK_interpolate2(t0, tf, t);
#ifdef DEBUG_TIMER
                  debug_timer(); // 5
#endif

                  leg1 = IK_final(x1.pos, yy1.pos, z1.pos);
                  leg2 = IK_final(x2.pos, yy2.pos, z2.pos);
                  leg3 = IK_final(x3.pos, yy3.pos, z3.pos);
                  leg4 = IK_final(x4.pos, yy4.pos, z4.pos);
#ifdef DEBUG_TIMER
                  debug_timer(); // 6
#endif

                  // write angles to servos
                  write_servos();

                  // debug
#ifdef PRINT_LEG_THETA
                  Serial.print(leg1.hip);
                  Serial.print("\t");
                  Serial.print(leg1.shoulder);
                  Serial.print("\t");
                  Serial.print(leg1.knee);
                  Serial.print("\t");
#endif
#ifdef DEBUG_SERIAL_PRINT
                  Serial.println("");
#endif
            }
      }

      if (mode == 4)
      {
            // timing control
            if (t - t_old_state >= state_time)
            {
                  t_old_state = t;
                  t0 = t;
                  tf = t0 + state_time;
                  state = 0;
                  // define leg positions
                  get_xyz();
            }

            // interpolation timing
            if (t - t_old >= interpolation_interval)
            {
                  t_old = t;
#ifdef PID_BALANCE_ENABLE
                  get_xyz();
#endif

                  // interpolate to final angles
                  IK_interpolate2(t0, tf, t);

                  leg1 = IK_final(x1.pos, yy1.pos, z1.pos);
                  leg2 = IK_final(x2.pos, yy2.pos, z2.pos);
                  leg3 = IK_final(x3.pos, yy3.pos, z3.pos);
                  leg4 = IK_final(x4.pos, yy4.pos, z4.pos);
                  // write angles to servos
                  write_servos();
            }
      }
}

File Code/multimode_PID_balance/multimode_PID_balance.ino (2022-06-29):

#include <Servo.h>
#include "I2Cdev.h"
#include "MPU6050_6Axis_MotionApps20.h"
#include "PID_v1.h"


//code control vars
int state_time = 1000;
int interpolation_interval;
int n_interps = 20;
int state = 1;
int mode = 0;
int n_states = 6;

//timing vars
int t0;
int tf;
int t;
int t_old;
int t_old_state;

//foot position vars
float L = 124;
float l_pitch = 156;
float l_roll = 76;
float x1;
float yy1;
float z1;
float x2;
float yy2;
float z2;
float x3;
float yy3;
float z3;
float x4;
float yy4;
float z4;

//leg position control vars
float x_dist = 0;
float z_dist = 0;
double steer1 = 0;
float steer2 = 0;
double pitch1 = 0;
double pitch_angle1 = 0;
float pitch2 = 0;
double pitch_angle2 = 0;
double roll1 = 0;
double roll_angle1 = 0;
float roll2 = 0;
double roll_angle2 = 0;
double yaw1;
float yaw2;
float step_height = 20;
float leg_height = 200;
int control_increment = 20;

double yaw;
double pitch;
double roll;

double yaw_desired = 0;
double pitch_desired = -2;//1
double roll_desired = 0;

//PID setup
float kup = 4.5;
float tup = 1*.01613;
float kpp = .05;//.45*kup;
float kip = 0.0;//.54*kup/tup;
float kdp = 0;//.54*kup*tup;
PID pitchPID(&pitch, &pitch_angle1, &pitch_desired, kpp, kip, kdp, DIRECT);
float kpr = .05;//.6;
float kir = 0.01;//.01;
float kdr = 0.01;//.04;
PID rollPID(&roll, &roll_angle1, &roll_desired, kpr, kir, kdr, DIRECT);
float kpy = 0.0;
float kiy = 0.0;
float kdy = 0.0;
PID yawPID(&yaw, &yaw1, &yaw_desired, kpy, kiy, kdy, DIRECT);

float kpp2 = 0;//.45*kup;
float kip2 = 0;//.54*kup/tup;
float kdp2 = 0;//.54*kup*tup;
PID pitch2PID(&pitch, &pitch_angle2, &pitch_desired, kpp2, kip2, kdp2, DIRECT);
float kpr2 = 0.0;
float kir2 = 0.0;
float kdr2 = 0.0;
PID roll2PID(&roll, &roll_angle2, &roll_desired, kpr2, kir2, kdr2, DIRECT);

/*
double aTuneStep=50, aTuneNoise=1, aTuneStartValue=100;
unsigned int aTuneLookBack=20;

boolean tuning = true;

PID_ATune aTune(&pitch, &pitch1);
*/

//remote control vars
int input;

bool newData = false;

//servo objects
Servo hip1;
Servo shoulder1;
Servo knee1; 
Servo hip2;
Servo shoulder2;
Servo knee2; 
Servo hip3;
Servo shoulder3;
Servo knee3; 
Servo hip4;
Servo shoulder4;
Servo knee4; 

//leg angle structure
struct angles{
  float hip;
  float shoulder;
  float knee;
};

struct angles leg1;
struct angles leg2;
struct angles leg3;
struct angles leg4;

struct angles leg1_final;
struct angles leg2_final;
struct angles leg3_final;
struct angles leg4_final;

//IMU setup
#if I2CDEV_IMPLEMENTATION == I2CDEV_ARDUINO_WIRE
    #include "Wire.h"
#endif

MPU6050 mpu;
#define OUTPUT_READABLE_YAWPITCHROLL

#define INTERRUPT_PIN 2  // use pin 2 on Arduino Uno & most boards

bool blinkState = false;

// MPU control/status vars
bool dmpReady = false;  // set true if DMP init was successful
uint8_t mpuIntStatus;   // holds actual interrupt status byte from MPU
uint8_t devStatus;      // return status after each device operation (0 = success, !0 = error)
uint16_t packetSize;    // expected DMP packet size (default is 42 bytes)
uint16_t fifoCount;     // count of all bytes currently in FIFO
uint8_t fifoBuffer[64]; // FIFO storage buffer

// orientation/motion vars
Quaternion q;           // [w, x, y, z]         quaternion container
VectorInt16 aa;         // [x, y, z]            accel sensor measurements
VectorInt16 aaReal;     // [x, y, z]            gravity-free accel sensor measurements
VectorInt16 aaWorld;    // [x, y, z]            world-frame accel sensor measurements
VectorFloat gravity;    // [x, y, z]            gravity vector
float euler[3];         // [psi, theta, phi]    Euler angle container
float ypr[3];           // [yaw, pitch, roll]   yaw/pitch/roll container and gravity vector

// indicates whether MPU interrupt pin has gone high
volatile bool mpuInterrupt = false;
void dmpDataReady() {
    mpuInterrupt = true;
}

//setup and initialization code
void setup() {
  //pin setup 
  pinMode(0, OUTPUT);
  pinMode(1, OUTPUT);
  pinMode(2, OUTPUT);
  pinMode(3, OUTPUT);
  pinMode(4, OUTPUT);
  pinMode(5, OUTPUT);
  pinMode(6, OUTPUT);
  pinMode(7, OUTPUT);
  pinMode(8, OUTPUT);
  pinMode(9, OUTPUT);
  pinMode(10, OUTPUT);
  pinMode(11, OUTPUT);
  pinMode(13, OUTPUT);

  //initialize servos
  hip1.attach(0);
  shoulder1.attach(1);
  knee1.attach(2);
  hip2.attach(3);
  shoulder2.attach(4);
  knee2.attach(5);
  hip3.attach(6);
  shoulder3.attach(7);
  knee3.attach(8);
  hip4.attach(9);
  shoulder4.attach(10);
  knee4.attach(11);

  digitalWrite(13, HIGH);
  //initialize serial bus
  Serial.begin(9600);

  //set initial leg position
  x1 = 0;
  yy1 = 0;
  z1 = leg_height;
  x2 = x1;
  yy2 = yy1;
  z2 = z1;
  x3 = x1;
  yy3 = yy1;
  z3 = z1;
  x4 = x1;
  yy4 = yy1;
  z4 = z1;

  //calculate inverse kinematics
  leg1 = IK_final(x1, yy1, z1);
  leg2 = IK_final(x2, yy2, z2);
  leg3 = IK_final(x3, yy3, z3);
  leg4 = IK_final(x4, yy4, z4);

  //write angles to servos 
  write_servos();
  
  //debug & calibrate servo angles
  /*
  leg1.hip = 0;
  leg1.shoulder = 45;
  leg1.knee = 90;  
  leg2.hip = 0;
  leg2.shoulder = 45;
  leg2.knee = 90; 
  leg3.hip = 0;
  leg3.shoulder = 45;
  leg3.knee = 90; 
  leg4.hip = 0;
  leg4.shoulder = 45;
  leg4.knee = 90;
  */


  //IMU setup
  Serial.print("IMU setup start");
  delay(2500);
  IMU_setup();
  Serial.print("IMU setup end");

  //sets # of points interpolated between servo positions: more = smoother
  interpolation_interval = state_time/n_interps;
  //PID start
  
  
  yawPID.SetMode(AUTOMATIC);
  yawPID.SetOutputLimits(-20, 20);
  yawPID.SetSampleTime(10);

  pitchPID.SetMode(AUTOMATIC);
  pitchPID.SetOutputLimits(-20, 20);
  pitchPID.SetSampleTime(100);
  pitch2PID.SetMode(AUTOMATIC);
  pitch2PID.SetOutputLimits(-100, 100);
  pitch2PID.SetSampleTime(100);
  
  rollPID.SetMode(AUTOMATIC);
  rollPID.SetOutputLimits(-20, 20);
  rollPID.SetSampleTime(100);
  roll2PID.SetMode(AUTOMATIC);
  roll2PID.SetOutputLimits(-30, 30);
  roll2PID.SetSampleTime(100);
  
  delay(5000); 
}
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

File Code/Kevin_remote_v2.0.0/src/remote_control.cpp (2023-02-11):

#include <remote_control.h>

template <class TYPE>
void packet_builder(char mnemon[7], char type, TYPE data_value)
{
  char time_bytes[4];
  byte mnemonic_bytes[7];
  byte type_byte[1];
  byte data_bytes[8];
  u_int16_t checksum = 0; // 2 bytes

  int comm_time = millis();

  memcpy(time_bytes, &comm_time, sizeof comm_time);
  memcpy(mnemonic_bytes, &mnemon, sizeof mnemonic_bytes);
  memcpy(type_byte, &type, sizeof type);
  memcpy(data_bytes, &data_value, 8);

  for (int i = 0; i < 4; i++)
  {
    checksum = checksum + time_bytes[i];
  }
  for (int i = 0; i < 7; i++)
  {
    checksum = checksum + mnemon[i];
  }

  checksum = checksum + type;
  for (int i = 0; i < 8; i++)
  {
    checksum = checksum + data_bytes[i];
  }

  byte checksum_bytes[2];
  memcpy(checksum_bytes, &checksum, sizeof checksum);

  // extern char telem_packet[24];

  telem_packet[0] = '<';
  telem_packet[1] = checksum_bytes[0];
  telem_packet[2] = checksum_bytes[1];
  telem_packet[3] = time_bytes[0];
  telem_packet[4] = time_bytes[1];
  telem_packet[5] = time_bytes[2];
  telem_packet[6] = time_bytes[3];
  telem_packet[7] = mnemon[0];
  telem_packet[8] = mnemon[1];
  telem_packet[9] = mnemon[2];
  telem_packet[10] = mnemon[3];
  telem_packet[11] = mnemon[4];
  telem_packet[12] = mnemon[5];
  telem_packet[13] = mnemon[6];
  telem_packet[14] = type;
  telem_packet[15] = data_bytes[0];
  telem_packet[16] = data_bytes[1];
  telem_packet[17] = data_bytes[2];
  telem_packet[18] = data_bytes[3];
  telem_packet[19] = data_bytes[4];
  telem_packet[20] = data_bytes[5];
  telem_packet[21] = data_bytes[6];
  telem_packet[22] = data_bytes[7];
  telem_packet[23] = '>';
}

/*
Packet list: all telemetry items sent out + their mnemonics
Each includes a time stamp
-time (for sync purposes?) 1  KEVTIME
-motor angles (target + actual) 12 (24) S1A_TAR S1A_ACT
-leg coords (target + actual) (24) L1X_POS L1Y_POS L1Z_POS L1XFPOS L1YFPOS L1ZFPOS
-rpy (3) ROLLVAL PIT_VAL YAW_VAL
-xyz accel (3) ACCEL_X ACCEL_Y ACCEL_Z
-mode (1) MODEVAL
-balance mode (1) BALMODE
-PID values (3) PIDVALP PIDVALI PIDVALD
-command positions (translate + yaw) (3) FWDMOVE SIDMOVE YAWMOVE

Mnemonic list
MH1A_TAR - leg 1 hip target angle
MH1A_ACT - leg 1 hip actual angle
MS1A_TAR - leg 1 shoulder target angle
MS1A_ACT - leg 1 shoulder actual angle
MK1A_TAR - leg 1 knee target angle
MK1A_ACT - leg 1 knee actual angle
MH2A_TAR - leg 2 hip target angle
MH2A_ACT - leg 2 hip actual angle
MS2A_TAR - leg 2 shoulder target angle
MS2A_ACT - leg 2 shoulder actual angle
MK2A_TAR - leg 2 knee target angle
MK2A_ACT - leg 2 knee actual angle
MH3A_TAR - leg 3 hip target angle
MH3A_ACT - leg 3 hip actual angle
MS3A_TAR - leg 3 shoulder target angle
MS3A_ACT - leg 3 shoulder actual angle
MK3A_TAR - leg 3 knee target angle
MK3A_ACT - leg 3 knee actual angle
MH4A_TAR - leg 4 hip target angle
MH4A_ACT - leg 4 hip actual angle
MS4A_TAR - leg 4 shoulder target angle
MS4A_ACT - leg 4 shoulder actual angle
MK4A_TAR - leg 4 knee target angle
MK4A_ACT - leg 4 knee actual angle
ML1X_POS - leg 1 x position
ML1Y_POS - leg 1 Y position
ML1Z_POS - leg 1 Z position
ML1XFPOS - leg 1 x final position
ML1YFPOS - leg 1 Y final position
ML1ZFPOS - leg 1 Z final position
ML2X_POS - leg 2 x position
ML2Y_POS - leg 2 Y position
ML2Z_POS - leg 2 Z position
ML2XFPOS - leg 2 x final position
ML2YFPOS - leg 2 Y final position
ML2ZFPOS - leg 2 Z final position
ML3X_POS - leg 3 x position
ML3Y_POS - leg 3 Y position
ML3Z_POS - leg 3 Z position
ML3XFPOS - leg 3 x final position
ML3YFPOS - leg 3 Y final position
ML3ZFPOS - leg 3 Z final position
ML4X_POS - leg 4 x position
ML4Y_POS - leg 4 Y position
ML4Z_POS - leg 4 Z position
ML4XFPOS - leg 4 x final position
ML4YFPOS - leg 4 Y final position
ML4ZFPOS - leg 4 Z final position
MROLLVAL - roll value
MPIT_VAL - pitch value
MYAW_VAL - yaw value
MACCEL_X - x acceleration
MACCEL_Y - y acceleration
MACCEL_Z - z acceleration
MMODEVAL - mode that Kevin is in
MBALMODE - type of balance being used
MPIDVLRP - PID roll proportional value
MPIDVLRI - PID roll integral value
MPIDVLRD - PID roll derivative value
MPIDVLPP - PID pitch proportional value
MPIDVLPI - PID pitch integral value
MPIDVLPD - PID pitch derivative value
MFWDMOVE - move forward value
MSIDMOVE - move sideways value
MYAWMOVE - rotate in place value
MSTEPSTE - state in walking motion

Mnemonics to add:
BATTLVL - Battery charge percentage
PCKT_TX - # of packets sent (may help if there's data loss)
PCKT_RX - # of packets recieved (may help if there's data loss)
ROLLCMD - attitude roll command
PIT_CMD - attitude pitch command
YAW_CMD - attitude yaw command
*/

/*
63 mnemonics

115 bits per millisecond
each character is 8 bits
14 bytes per millisecond

T0000000MXXXXXXXD0000000E (2 milliseconds per packet)

1Hz data (1000ms)
PIDVLRP - PID roll proportional value
PIDVLRI - PID roll integral value
PIDVLRD - PID roll derivative value
PIDVLPP - PID pitch proportional value
PIDVLPI - PID pitch integral value
PIDVLPD - PID pitch derivative value
MODEVAL - mode that Kevin is in
BALMODE - type of balance being used
KEVTIME - time onboard Kevin (milliseconds)

4Hz data (250ms)
FWDMOVE - move forward value
SIDMOVE - move sideways value
YAWMOVE - rotate in place value
ACCEL_X - x acceleration
ACCEL_Y - y acceleration
ACCEL_Z - z acceleration
YAW_VAL - yaw value

40Hz data (25ms) (350 bytes)
ROLLVAL - roll value
PIT_VAL - pitch value
STEPSTE - state in walking motion
H1A_TAR - leg 1 hip target angle
S1A_TAR - leg 1 shoulder target angle
K1A_TAR - leg 1 knee target angle
L1X_POS - leg 1 x position
L1Y_POS - leg 1 Y position
L1Z_POS - leg 1 Z position
*/

#ifdef COMM_MODE_DESCRIPTIVE

void comms_send()
{
  int comm_time = millis();

#ifdef COMM_ROLE_VEHICLE
#ifdef SEND_RPY
  memset(telem_packet, 0, 24);
  if ((comm_time % 50) == 0)
  {
    // Serial.println(Serial4.availableForWrite());
    // ROLLVAL - IMU roll value
    packet_builder("ROLLVAL", 'd', roll);
    Serial4.write(telem_packet, 24);
  }
  else if ((comm_time % 50) == 8)
  {
    // PIT_VAL - IMU pitch value
    packet_builder("PIT_VAL", 'd', pitch);
    Serial4.write(telem_packet, 24);
  }
  else if ((comm_time % 50) == 16)
  {
    // YAW_VAL - IMU yaw value
    packet_builder("YAW_VAL", 'd', yaw);
    Serial4.write(telem_packet, 24);
  }
#endif

  memset(telem_packet, 0, 24);
  if ((comm_time % 50) == 24)
  {
    // STEPSTE - state in walking motion
    packet_builder("STEPSTE", 'i', state);
    Serial4.write(telem_packet, 24);
  }
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

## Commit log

2022-07-18 Migration from Arduino to PIO
    - migrated project from arduino IDE to PlatformIO in Vscode
    - code reorganized to split functions into separate files
    - added basic remote control functionality using bluetooth serial
    [configuration.h]
2022-07-18 moved CAD files
    [Channel Bracket.SLDPRT, MirrorMirrorMulti Purpose Bracket.SLDPRT, MirrorMirrorU Long Bracket.SLDPRT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]
2022-07-27 Foot Trajectory Changes & bug fixes
    modified foot trajectories, bug-fixed interpolation & remote communications
    [configuration.h]
2022-07-27 Part Redesign
    [electronics_mount.SLDPRT]
2023-01-28 latest changes
    [configuration.h]
2023-02-03 comms overhaul
    [configuration.h]
2023-02-06 remote control changes sync, full transmission packetlist
    [configuration.h]
2023-02-11 attitude control major changes
    [configuration.h]
